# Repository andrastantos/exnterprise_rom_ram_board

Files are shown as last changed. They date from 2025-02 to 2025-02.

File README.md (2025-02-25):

A 512kB RAM and ROM expansion design for the Enterprise computer
===================================================================

This design can be used to add up to 512kB of ROM as well as 512kB of RAM without using up any external connectors of the computer.
It can also be used (by populating the ROM socket with a second RAM chip) to add 1MB of RAM to the machine.

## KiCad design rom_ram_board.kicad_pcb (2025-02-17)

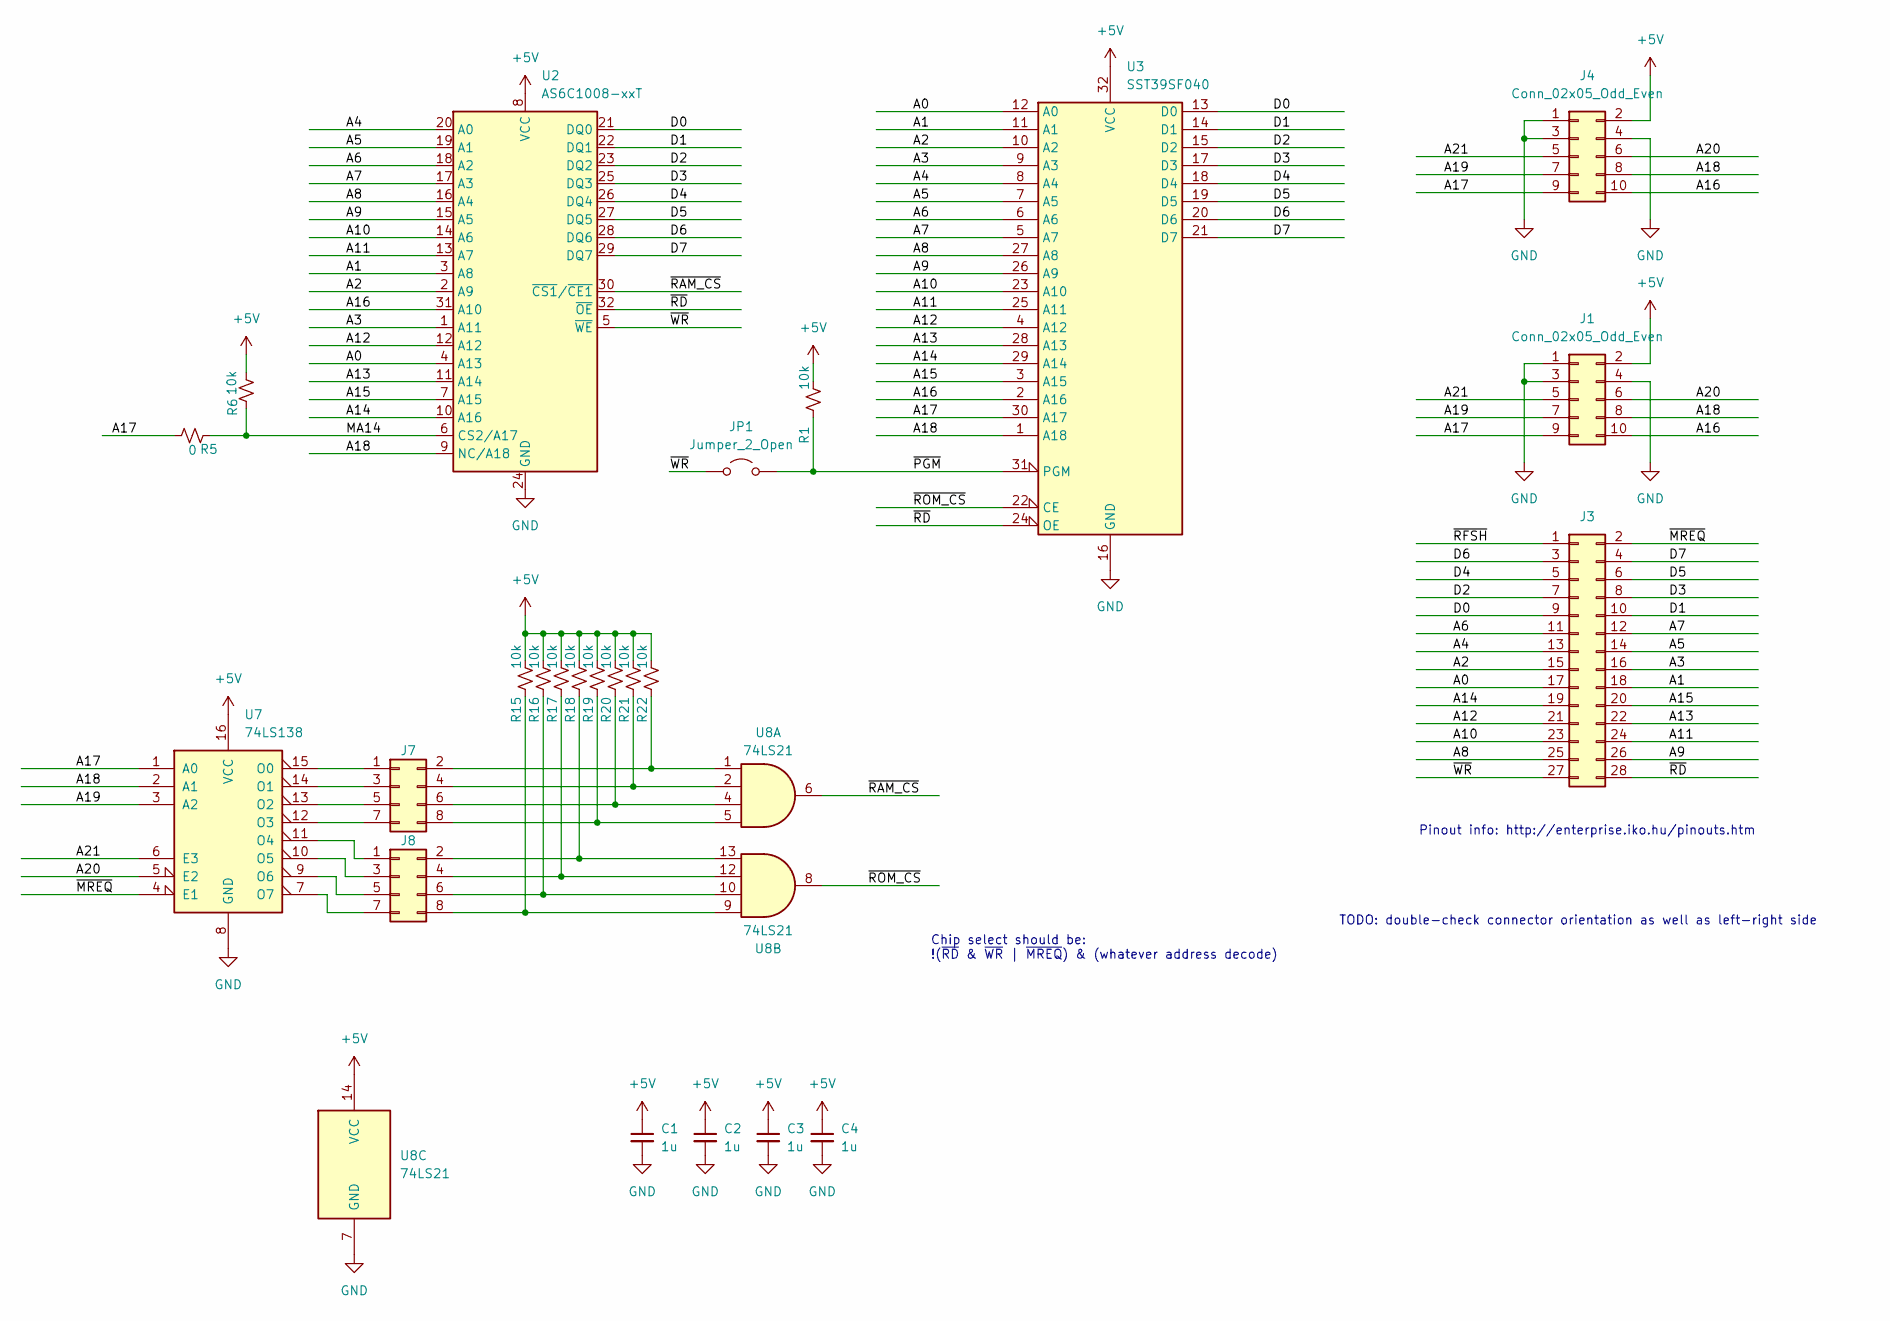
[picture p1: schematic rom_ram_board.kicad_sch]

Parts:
C1, C2, C3, C4: 1u; C_0603_1608Metric_Pad1.08x0.95mm_HandSolder
J1: Conn_02x05_Odd_Even; PinHeader_2x05_P2.54mm_Vertical
J3: Conn_02x16_Row_Letter_First; PinSocket_2x14_P2.54mm_Vertical
J4: Conn_02x05_Odd_Even; PinSocket_2x05_P2.54mm_Vertical
J7, J8: Conn_02x02_Odd_Even; PinHeader_2x04_P2.54mm_Vertical
JP1: Jumper_2_Open; PinHeader_1x02_P2.54mm_Vertical
R1, R6, R15, R16, R17, R18, R19, R20, R21, R22: 10k; R_0603_1608Metric_Pad0.98x0.95mm_HandSolder
R5: 0; R_0603_1608Metric_Pad0.98x0.95mm_HandSolder
U2: AS6C1008-xxT; TSOP-I-32_11-18.4x8mm_P0.5mm
U3: SST39SF040; DIP-32_W15.24mm_Socket_LongPads
U7: 74LS138; SO-16_3.9x9.9mm_P1.27mm
U8: 74LS21; SO-14_3.9x8.65mm_P1.27mm

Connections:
+5V: C1.1, C2.1, C3.1, C4.1, J1.2, J4.2, R1.1, R6.1, R15.1, R16.1, R17.1, R18.1, R19.1, R20.1, R21.1, R22.1, U2.8 (VCC), U3.32 (VCC), U7.16 (VCC), U8.14 (VCC)
/A0: J3.17, U2.4 (A13), U3.12 (A0)
/A1: J3.18, U2.3 (A8), U3.11 (A1)
/A2: J3.15, U2.2 (A9), U3.10 (A2)
/A3: J3.16, U2.1 (A11), U3.9 (A3)
/A4: J3.13, U2.20 (A0), U3.8 (A4)
/A5: J3.14, U2.19 (A1), U3.7 (A5)
/A6: J3.11, U2.18 (A2), U3.6 (A6)
/A7: J3.12, U2.17 (A3), U3.5 (A7)
/A8: J3.25, U2.16 (A4), U3.27 (A8)
/A9: J3.26, U2.15 (A5), U3.26 (A9)
/A10: J3.23, U2.14 (A6), U3.23 (A10)
/A11: J3.24, U2.13 (A7), U3.25 (A11)
/A12: J3.21, U2.12 (A12), U3.4 (A12)
/A13: J3.22, U2.11 (A14), U3.28 (A13)
/A14: J3.19, U2.10 (A16), U3.29 (A14)
/A15: J3.20, U2.7 (A15), U3.3 (A15)
/A16: J1.10, J4.10, U2.31 (A10), U3.2 (A16)
/A17: J1.9, J4.9, R5.1, U3.30 (A17), U7.1 (A0)
/A18: J1.8, J4.8, U2.9 (NC/A18), U3.1 (A18), U7.2 (A1)
/A19: J1.7, J4.7, U7.3 (A2)
/A20: J1.6, J4.6, U7.5 (E2)
/A21: J1.5, J4.5, U7.6 (E3)
/D0: J3.9, U2.21 (DQ0), U3.13 (D0)
/D1: J3.10, U2.22 (DQ1), U3.14 (D1)
/D2: J3.7, U2.23 (DQ2), U3.15 (D2)
/D3: J3.8, U2.25 (DQ3), U3.17 (D3)
/D4: J3.5, U2.26 (DQ4), U3.18 (D4)
/D5: J3.6, U2.27 (DQ5), U3.19 (D5)
/D6: J3.3, U2.28 (DQ6), U3.20 (D6)
/D7: J3.4, U2.29 (DQ7), U3.21 (D7)
/MA14: R5.2, R6.2, U2.6 (CS2/A17)
/~MREQ: J3.2, U7.4 (E1)
/~PGM: JP1.2 (B), R1.2, U3.31 (PGM)
/~RAM_CS: U2.30 (~CS1/~CE1), U8.6
/~RD: J3.28, U2.32 (~OE), U3.24 (OE)
/~RFSH: J3.1
/~ROM_CS: U3.22 (CE), U8.8
/~WR: J3.27, JP1.1 (A), U2.5 (~WE)
GND: C1.2, C2.2, C3.2, C4.2, J1.1, J1.3, J1.4, J4.1, J4.3, J4.4, U2.24 (GND), U3.16 (GND), U7.8 (GND), U8.7 (GND)
unnamed: J7.1, U7.15 (O0)
unnamed: J7.2, R22.2, U8.1
unnamed: J7.3, U7.14 (O1)
unnamed: J7.4, R21.2, U8.2
unnamed: J7.5, U7.13 (O2)
unnamed: J7.6, R20.2, U8.4
unnamed: J7.7, U7.12 (O3)
unnamed: J7.8, R19.2, U8.5
unnamed: J8.1, U7.11 (O4)
unnamed: J8.2, R18.2, U8.13
unnamed: J8.3, U7.10 (O5)
unnamed: J8.4, R17.2, U8.12
unnamed: J8.5, U7.9 (O6)
unnamed: J8.6, R16.2, U8.10
unnamed: J8.7, U7.7 (O7)
unnamed: J8.8, R15.2, U8.9

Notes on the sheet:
TODO: double-check connector orientation as well as left-right side
Pinout info: http://enterprise.iko.hu/pinouts.htm
Chip select should be: !(~{RD} & ~{WR} | ~{MREQ}) & (whatever address decode)

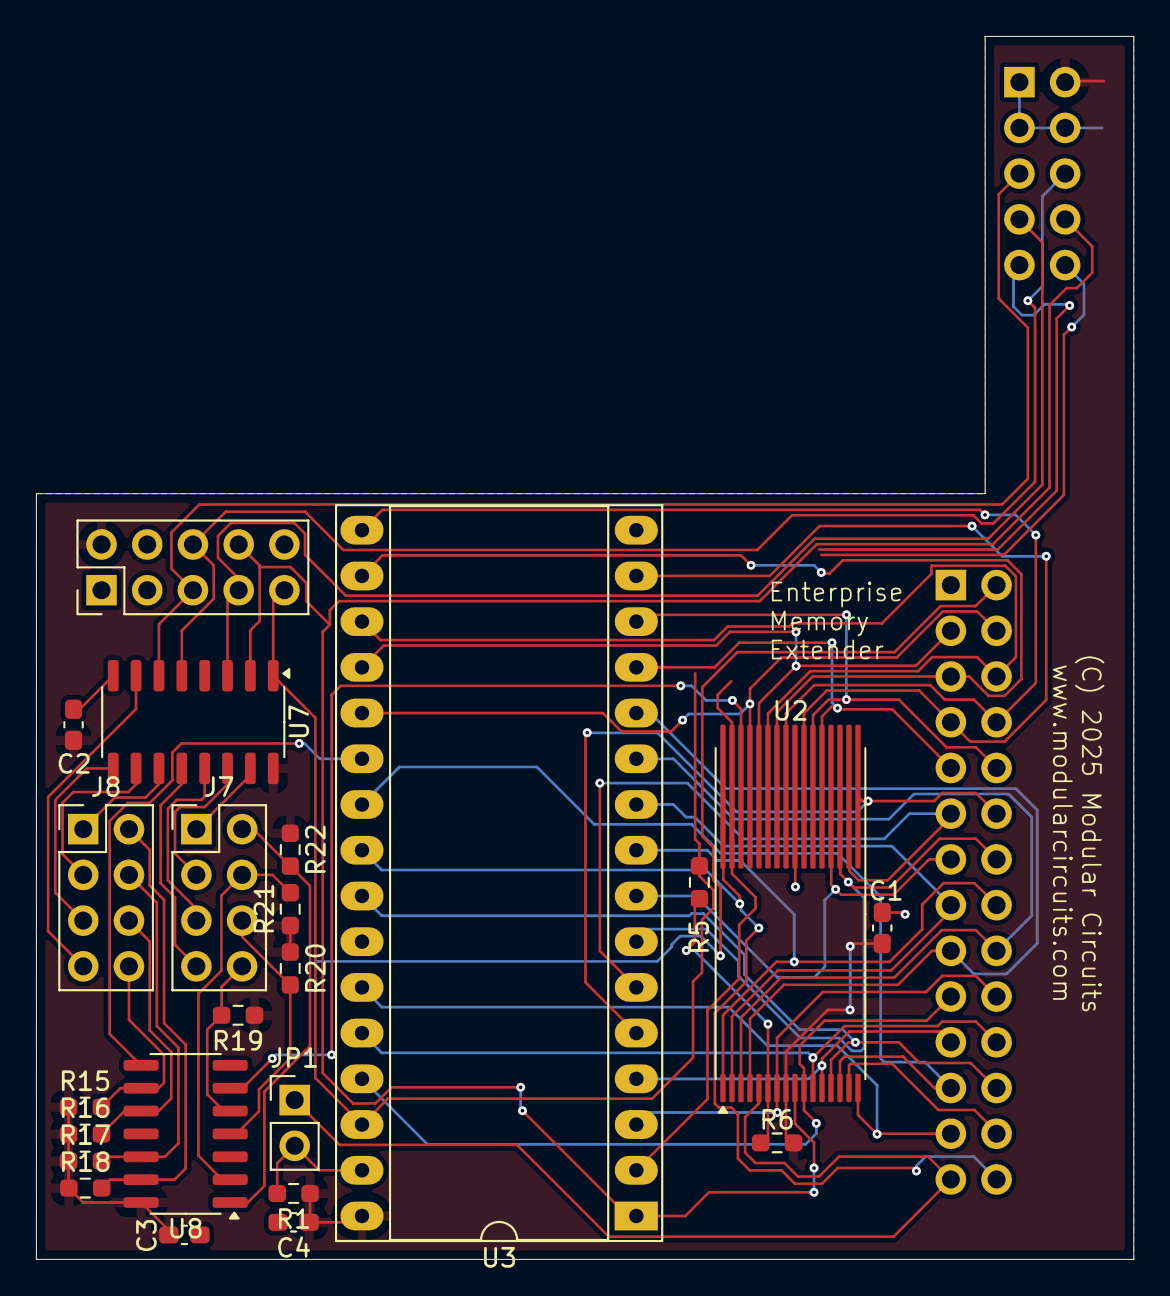
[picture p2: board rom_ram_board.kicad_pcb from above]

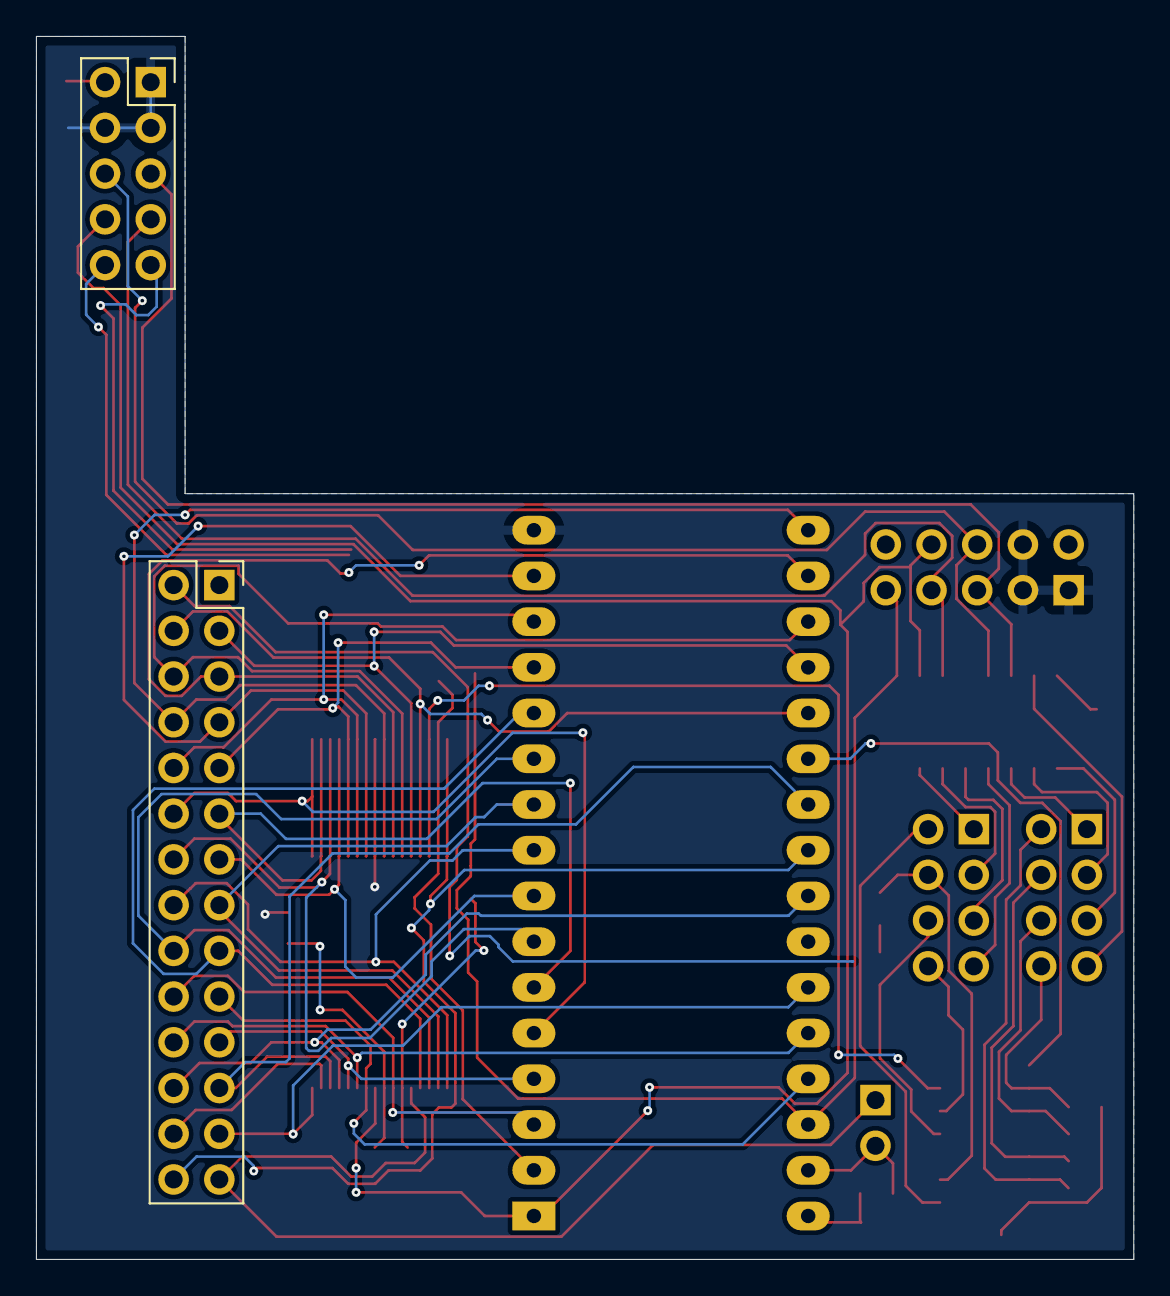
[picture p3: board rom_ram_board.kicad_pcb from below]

Board: 2 copper layers, 61.0 x 67.9 mm, 25 parts (2 on the bottom side), 55 nets.

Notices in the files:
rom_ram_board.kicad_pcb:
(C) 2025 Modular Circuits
